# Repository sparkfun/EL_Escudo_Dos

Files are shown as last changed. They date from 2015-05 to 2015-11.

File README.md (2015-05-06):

SparkFun EL Escudo Dos
========================================

SparkFun EL Escudo Dos

[*SparkFun EL Escudo Dos (COM-10878)*](https://www.sparkfun.com/products/10878)

The SparkFun EL Escudo Dos is an Arduino shield for controlling up to eight strands of electroluminescent wire. 
EL wire is flexible plastic cord that glows brightly when high-voltage AC is applied to it.
The El Escudo Dos contains circuitry to safely switch high-voltage AC on and off, allowing you to create animated displays or whatever else your imagination can come up with.

Repository Contents
-------------------

* **/Firmware** - Example code 
* **/Hardware** - Eagle design files (.brd, .sch)
* **/Production** - Production panel files (.brd)

Documentation
--------------
* **[Hookup Guide](https://www.sparkfun.com/tutorials/353)** - Basic hookup guide for the EL Escudo Dos.
* **[SparkFun Fritzing repo](https://github.com/sparkfun/Fritzing_Parts)** - Fritzing diagrams for SparkFun products.
* **[SparkFun 3D Model repo](https://github.com/sparkfun/3D_Models)** - 3D models of SparkFun products. 

License Information
-------------------
This product is _**open source**_! 

The **hardware** is released under [Creative Commons ShareAlike 4.0 International](https://creativecommons.org/licenses/by-sa/4.0/).

The **code** is beerware; if you see me (or any other SparkFun employee) at the local, and you've found our code helpful, please buy us a round!

Please use, reuse, and modify these files as you see fit. Please maintain attribution to SparkFun Electronics and release anything derivative under the same license.

Distributed as-is; no warranty is given.

- Your friends at SparkFun.

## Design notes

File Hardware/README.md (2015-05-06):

SparkFun <PRODUCT NAME> Design Files
=====================================

The .sch and .brd files hare are Eagle CAD schematic and PCB design files from SparkFun Electronics.
A freeware version of Eagle can be found [here](http://www.cadsoftusa.com/download-eagle/freeware/). 

License
---------
This product is open source! 
The hardware is released under [Creative Commons ShareAlike 4.0 International](https://creativecommons.org/licenses/by-sa/4.0/).

Please use, reuse, and modify these files as you see fit. Please maintain attribution to SparkFun Electronics and release anything derivative under the same license.

Distributed as-is; no warranty is given.

- Your friends at SparkFun.

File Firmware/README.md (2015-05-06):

SparkFun EL Escudo Dos Firmware
===================================

* **SparkFun_EL_Example** - Arduino example for the EL Escudo Dos Shield

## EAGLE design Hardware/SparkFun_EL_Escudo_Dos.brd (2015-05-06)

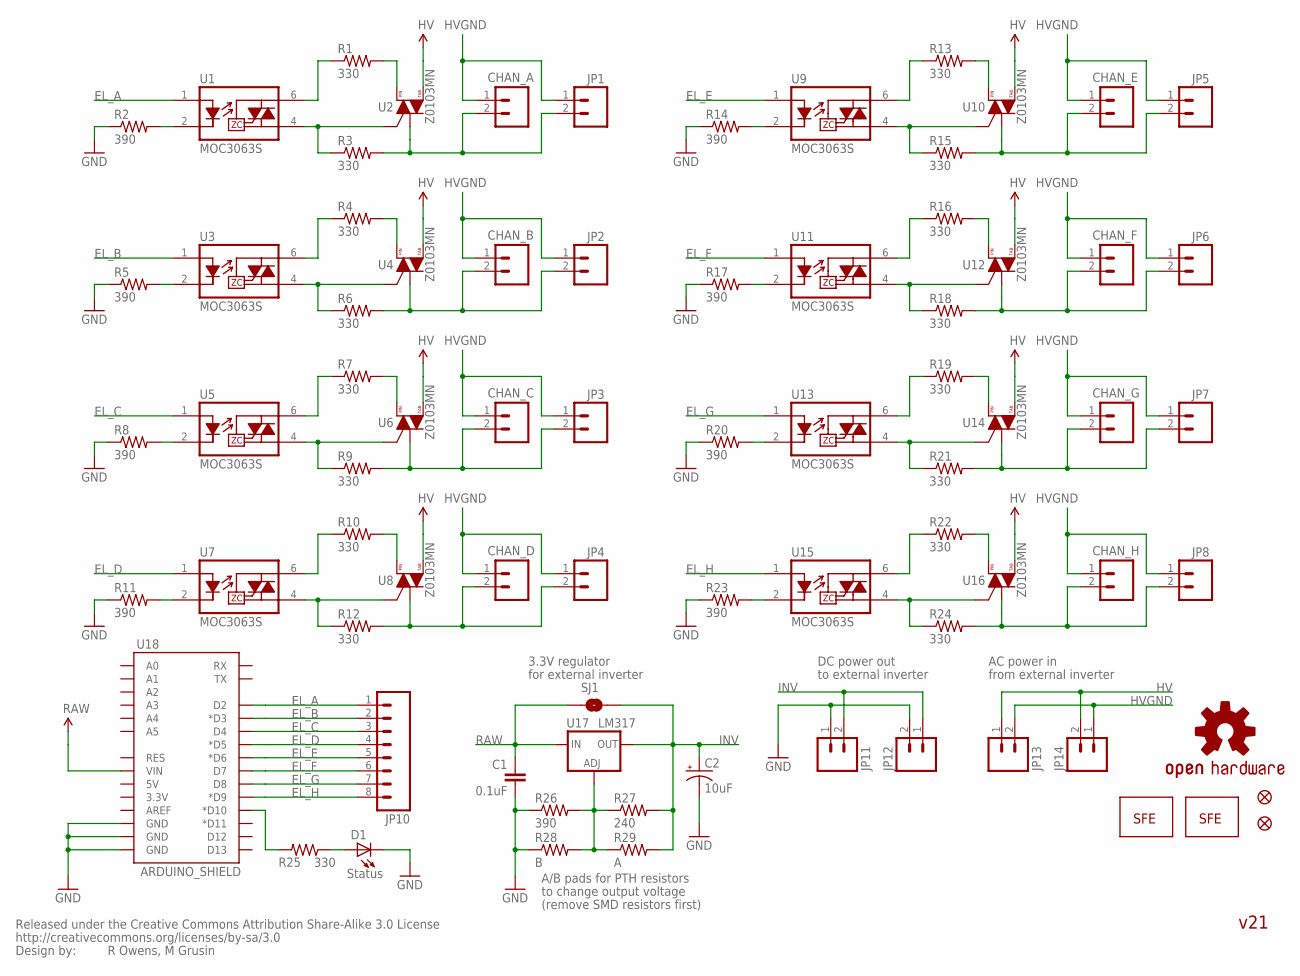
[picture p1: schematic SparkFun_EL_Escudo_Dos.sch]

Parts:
C1: 0.1uF; 0603-CAP
C2: 10uF; EIA3216
CHAN_A: M02-JST-2MM-SMT; JST-2-SMD
CHAN_B: M02-JST-2MM-SMT; JST-2-SMD
CHAN_C: M02-JST-2MM-SMT; JST-2-SMD
CHAN_D: M02-JST-2MM-SMT; JST-2-SMD
CHAN_E: M02-JST-2MM-SMT; JST-2-SMD
CHAN_F: M02-JST-2MM-SMT; JST-2-SMD
CHAN_G: M02-JST-2MM-SMT; JST-2-SMD
CHAN_H: M02-JST-2MM-SMT; JST-2-SMD
D1: Status; LED-0603
JP1, JP2, JP3, JP4, JP5, JP6, JP7, JP8, JP12, JP13: M02PTH; 1X02
JP9, JP15: LOGO-SFENEW; SFE-NEW-WEBLOGO
JP10: M081X08; 1X08
JP11, JP14: M02-JST-2MM-SMT; JST-2-SMD
JP16, JP17: FIDUCIALUFIDUCIAL; MICRO-FIDUCIAL
R1, R3, R4, R6, R7, R9, R10, R12, R13, R15, R16, R18, R19, R21, R22, R24, R25: 330; 0603-RES
R2, R5, R8, R11, R14, R17, R20, R23, R26: 390; 0603-RES
R27: 240; 0603-RES
R28: B; AXIAL-0.4
R29: A; AXIAL-0.4
SJ1: SOLDERJUMPERNO; SJ_2S-NO
U1, U3, U5, U7, U9, U11, U13, U15: MOC3063S; DIP8SMD
U2, U4, U6, U8, U10, U12, U14, U16: Z0103MN; SOT223
U17: LM317; V-REG_DPACK
U18: ARDUINO_SHIELD; DUEMILANOVE_SHIELD_NOLABELS
U$4: CREATIVE_COMMONS
U$5: OSHW-LOGOS; OSHW-LOGO-S

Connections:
EL_A: JP10.1, U1.1 (A), U18.D2
EL_B: JP10.2, U3.1 (A), U18.D3 (*D3)
EL_C: JP10.3, U5.1 (A), U18.D4
EL_D: JP10.4, U7.1 (A), U18.D5 (*D5)
EL_E: JP10.5, U9.1 (A), U18.D6 (*D6)
EL_F: JP10.6, U11.1 (A), U18.D7
EL_G: JP10.7, U13.1 (A), U18.D8
EL_H: JP10.8, U15.1 (A), U18.D9 (*D9)
GND: C1.2, C2.C (-), D1.C, JP11.1, JP12.2, R2.1, R5.1, R8.1, R11.1, R14.1, R17.1, R20.1, R23.1, R26.1, R28.P$1 (1), U18.GND@0 (GND), U18.GND@1 (GND), U18.GND@2 (GND)
HV: JP13.1, JP14.2, U2.4 (T2), U4.4 (T2), U6.4 (T2), U8.4 (T2), U10.4 (T2), U12.4 (T2), U14.4 (T2), U16.4 (T2)
HVGND: CHAN_A.1, CHAN_B.1, CHAN_C.1, CHAN_D.1, CHAN_E.1, CHAN_F.1, CHAN_G.1, CHAN_H.1, JP1.1, JP2.1, JP3.1, JP4.1, JP5.1, JP6.1, JP7.1, JP8.1, JP13.2, JP14.1
INV: C2.A (+), JP11.2, JP12.1, R27.2, R29.P$2 (2), SJ1.2, U17.4 (OUT)
unnamed: R2.2, U1.2 (K)
unnamed: R26.2, R27.1, R28.P$2 (2), R29.P$1 (1), U17.1 (ADJ)
unnamed: R1.1, U1.6 (T1)
unnamed: R25.2, U18.D10 (*D10)
unnamed: R6.1, U3.4 (T2), U4.3 (G)
unnamed: R5.2, U3.2 (K)
unnamed: R4.1, U3.6 (T1)
unnamed: CHAN_B.2, JP2.2, R6.2, U4.1 (T1)
unnamed: R1.2, U2.2 (T2)
unnamed: R9.1, U5.4 (T2), U6.3 (G)
unnamed: R8.2, U5.2 (K)
unnamed: R7.1, U5.6 (T1)
unnamed: CHAN_C.2, JP3.2, R9.2, U6.1 (T1)
unnamed: D1.A, R25.1
unnamed: R4.2, U4.2 (T2)
unnamed: R12.1, U7.4 (T2), U8.3 (G)
unnamed: R11.2, U7.2 (K)
unnamed: R10.1, U7.6 (T1)
unnamed: CHAN_D.2, JP4.2, R12.2, U8.1 (T1)
unnamed: R7.2, U6.2 (T2)
unnamed: CHAN_A.2, JP1.2, R3.2, U2.1 (T1)
unnamed: R15.1, U9.4 (T2), U10.3 (G)
unnamed: R14.2, U9.2 (K)
unnamed: R13.1, U9.6 (T1)
unnamed: CHAN_E.2, JP5.2, R15.2, U10.1 (T1)
unnamed: R10.2, U8.2 (T2)
unnamed: R18.1, U11.4 (T2), U12.3 (G)
unnamed: R17.2, U11.2 (K)
unnamed: R16.1, U11.6 (T1)
unnamed: CHAN_F.2, JP6.2, R18.2, U12.1 (T1)
unnamed: R13.2, U10.2 (T2)
unnamed: R21.1, U13.4 (T2), U14.3 (G)
unnamed: R20.2, U13.2 (K)
unnamed: R19.1, U13.6 (T1)
unnamed: CHAN_G.2, JP7.2, R21.2, U14.1 (T1)
unnamed: R16.2, U12.2 (T2)
unnamed: R24.1, U15.4 (T2), U16.3 (G)
unnamed: R23.2, U15.2 (K)
unnamed: R22.1, U15.6 (T1)
unnamed: CHAN_H.2, JP8.2, R24.2, U16.1 (T1)
unnamed: R19.2, U14.2 (T2)
unnamed: R22.2, U16.2 (T2)
unnamed: R3.1, U1.4 (T2), U2.3 (G)
RAW: C1.1, SJ1.1, U17.3 (IN), U18.VIN

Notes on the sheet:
AC power in
from external inverter
DC power out
to external inverter
3.3V regulator
R Owens, M Grusin
for external inverter
A/B pads for PTH resistors
to change output voltage
(remove SMD resistors first)
v21

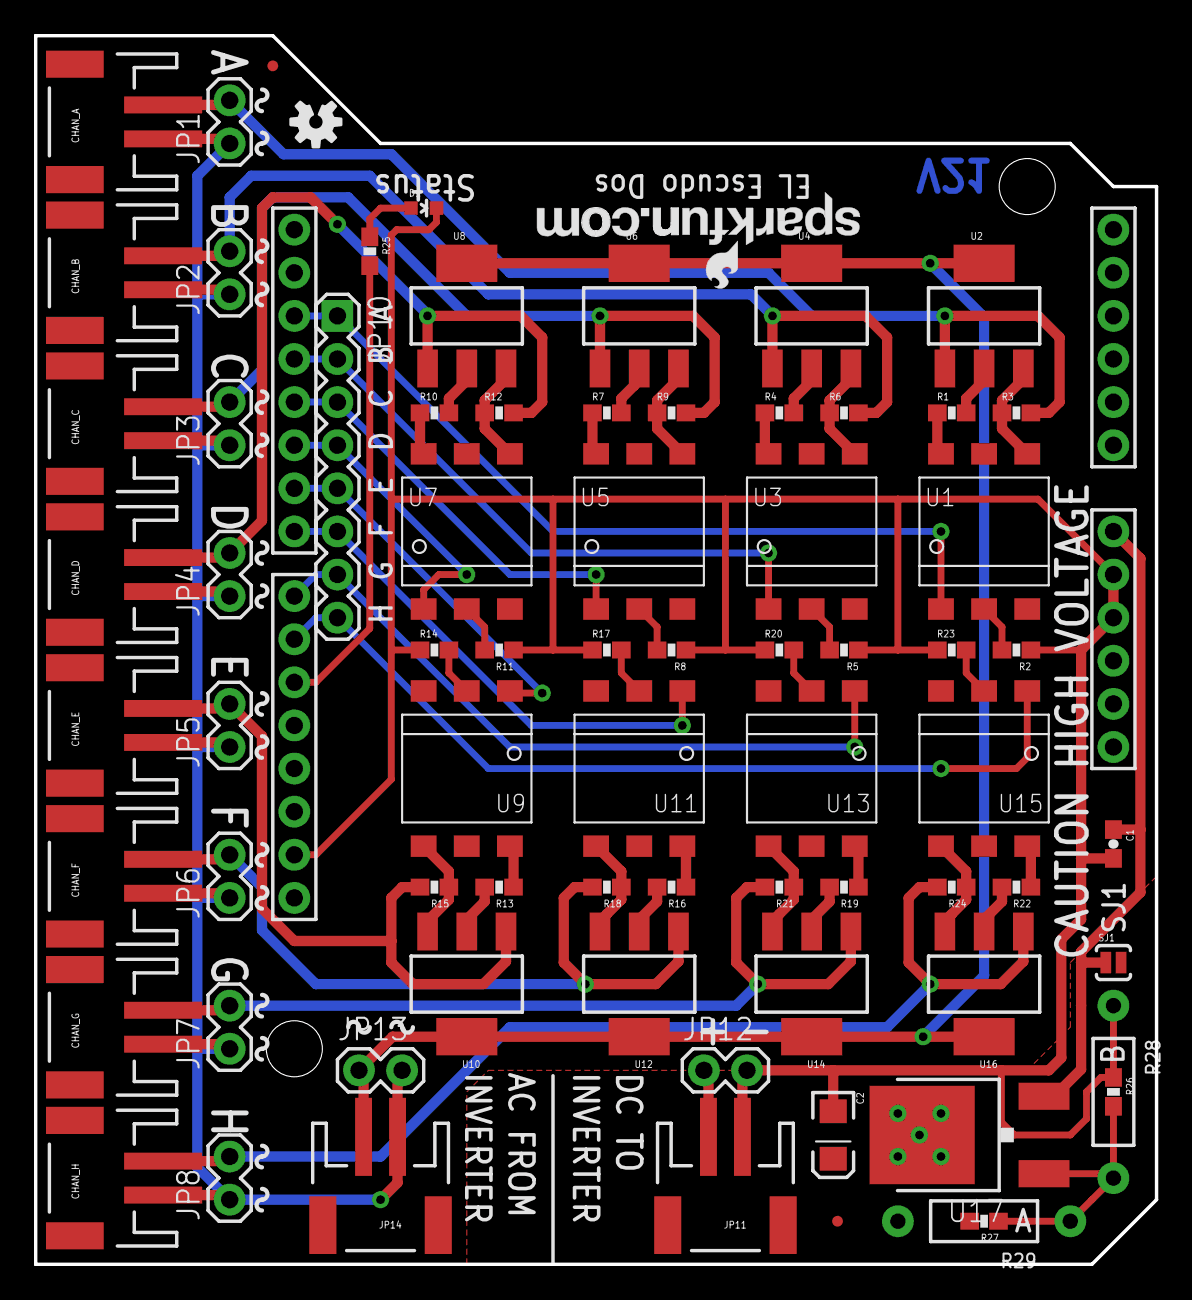
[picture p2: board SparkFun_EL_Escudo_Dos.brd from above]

Board: 2 copper layers, 66.0 x 72.4 mm, 78 parts (1 on the bottom side), 56 nets.

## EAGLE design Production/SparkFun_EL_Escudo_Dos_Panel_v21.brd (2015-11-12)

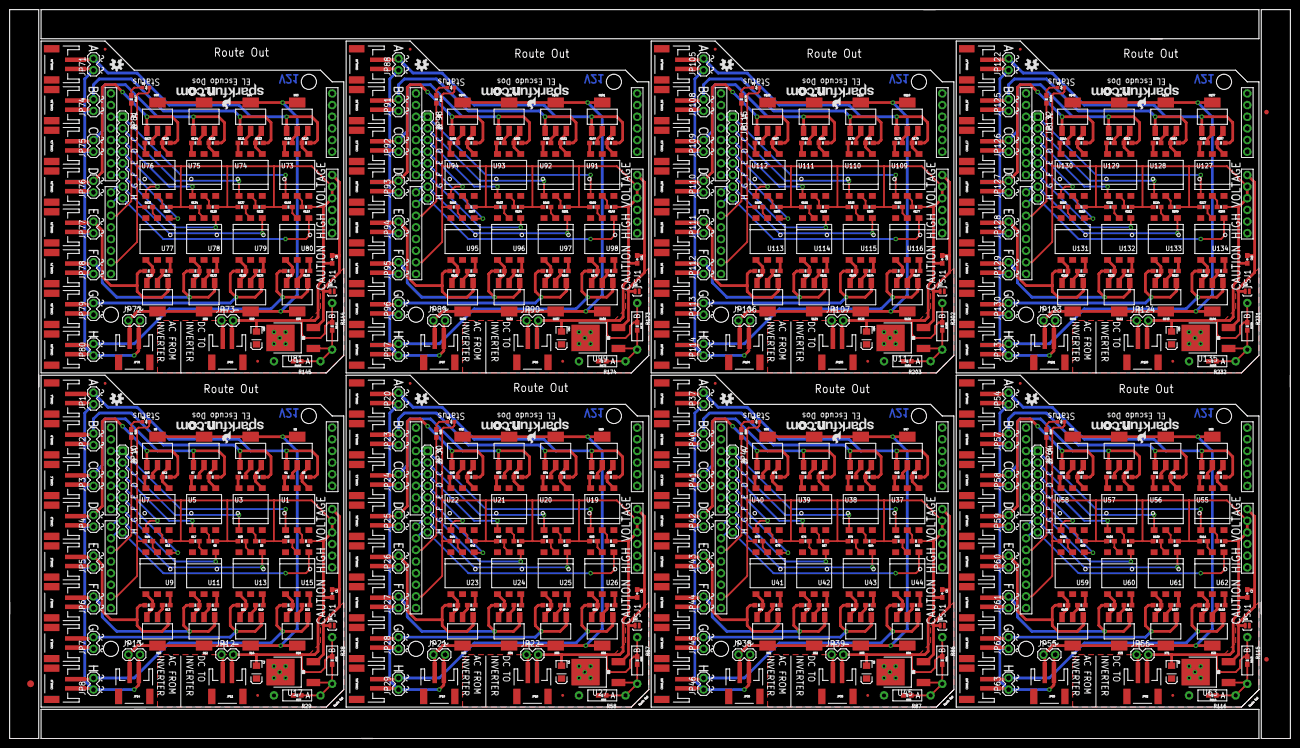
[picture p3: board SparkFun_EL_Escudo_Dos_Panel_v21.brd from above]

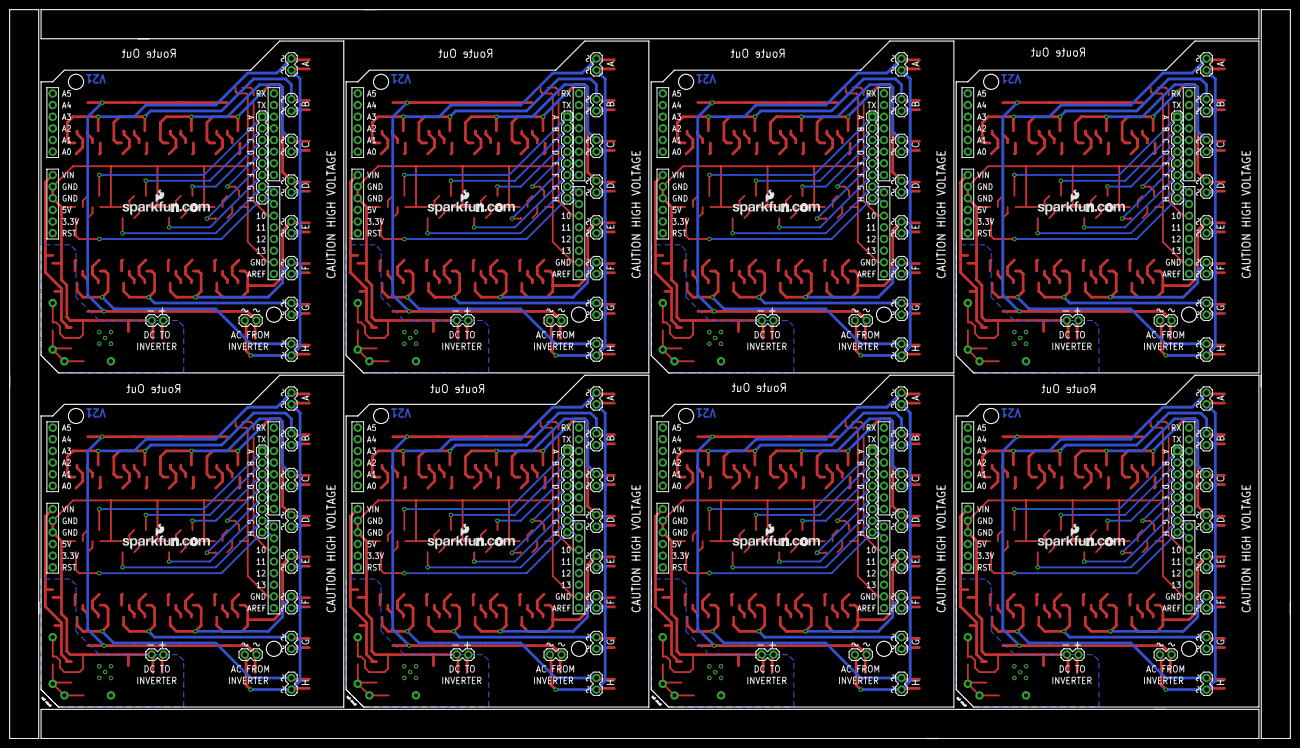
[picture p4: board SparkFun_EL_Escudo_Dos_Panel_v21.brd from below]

Board: 2 copper layers, 279.4 x 159.0 mm, 619 parts (8 on the bottom side), 448 nets.

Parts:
C1, C3, C5, C7, C9, C11, C13, C15: 0.1uF; 0603-CAP
C2, C4, C6, C8, C10, C12, C14, C16: 10uF; EIA3216
CHAN_A, CHAN_A1, CHAN_A2, CHAN_A3, CHAN_A4, CHAN_A5, CHAN_A6, CHAN_A7: JST-2-SMD
CHAN_B, CHAN_B1, CHAN_B2, CHAN_B3, CHAN_B4, CHAN_B5, CHAN_B6, CHAN_B7: JST-2-SMD
CHAN_C, CHAN_C1, CHAN_C2, CHAN_C3, CHAN_C4, CHAN_C5, CHAN_C6, CHAN_C7: JST-2-SMD
CHAN_D, CHAN_D1, CHAN_D2, CHAN_D3, CHAN_D4, CHAN_D5, CHAN_D6, CHAN_D7: JST-2-SMD
CHAN_E, CHAN_E1, CHAN_E2, CHAN_E3, CHAN_E4, CHAN_E5, CHAN_E6, CHAN_E7: JST-2-SMD
CHAN_F, CHAN_F1, CHAN_F2, CHAN_F3, CHAN_F4, CHAN_F5, CHAN_F6, CHAN_F7: JST-2-SMD
CHAN_G, CHAN_G1, CHAN_G2, CHAN_G3, CHAN_G4, CHAN_G5, CHAN_G6, CHAN_G7: JST-2-SMD
CHAN_H, CHAN_H1, CHAN_H2, CHAN_H3, CHAN_H4, CHAN_H5, CHAN_H6, CHAN_H7: JST-2-SMD
D1, D2, D3, D4, D5, D6, D7, D8: Status; LED-0603
E$1: FIDUCIAL-1.5X3
E$5, E$6: FIDUCIAL-1X2
JP1, JP2, JP3, JP4, JP5, JP6, JP7, JP8, JP12, JP13, JP20, JP21, JP22, JP23, JP24, JP25, JP26, JP27, JP28, JP29, JP37, JP38, JP39, JP40, JP41, JP42, JP43, JP44, JP45, JP46, JP54, JP55, JP56, JP57, JP58, JP59, JP60, JP61, JP62, JP63, JP71, JP72, JP73, JP74, JP75, JP76, JP77, JP78, JP79, JP80, JP88, JP89, JP90, JP91, JP92, JP93, JP94, JP95, JP96, JP97, JP105, JP106, JP107, JP108, JP109, JP110, JP111, JP112, JP113, JP114, JP122, JP123, JP124, JP125, JP126, JP127, JP128, JP129, JP130, JP131: 1X02
JP9, JP15, JP31, JP32, JP48, JP49, JP65, JP66, JP82, JP83, JP99, JP100, JP116, JP117, JP133, JP134: LOGO-SFENEW; SFE-NEW-WEBLOGO
JP10, JP30, JP47, JP64, JP81, JP98, JP115, JP132: 1X08
JP11, JP14, JP18, JP19, JP35, JP36, JP52, JP53, JP69, JP70, JP86, JP87, JP103, JP104, JP120, JP121: JST-2-SMD
JP16, JP17, JP33, JP34, JP50, JP51, JP67, JP68, JP84, JP85, JP101, JP102, JP118, JP119, JP135, JP136: FIDUCIALUFIDUCIAL; MICRO-FIDUCIAL
R1, R3, R4, R6, R7, R9, R10, R12, R13, R15, R16, R18, R19, R21, R22, R24, R25, R30, R31, R33, R34, R36, R37, R39, R40, R42, R43, R45, R46, R48, R49, R51, R52, R54, R59, R60, R62, R63, R65, R66, R68, R69, R71, R72, R74, R75, R77, R78, R80, R81, R83, R88, R89, R91, R92, R94, R95, R97, R98, R100, R101, R103, R104, R106, R107, R109, R110, R112, R117, R118, R120, R121, R123, R124, R126, R127, R129, R130, R132, R133, R135, R136, R138, R139, R141, R146, R147, R149, R150, R152, R153, R155, R156, R158, R159, R161, R162, R164, R165, R167, R168, R170, R175, R176, R178, R179, R181, R182, R184, R185, R187, R188, R190, R191, R193, R194, R196, R197, R199, R204, R205, R207, R208, R210, R211, R213, R214, R216, R217, R219, R220, R222, R223, R225, R226, R228: 330; 0603-RES
R2, R5, R8, R11, R14, R17, R20, R23, R26, R32, R35, R38, R41, R44, R47, R50, R53, R55, R61, R64, R67, R70, R73, R76, R79, R82, R84, R90, R93, R96, R99, R102, R105, R108, R111, R113, R119, R122, R125, R128, R131, R134, R137, R140, R142, R148, R151, R154, R157, R160, R163, R166, R169, R171, R177, R180, R183, R186, R189, R192, R195, R198, R200, R206, R209, R212, R215, R218, R221, R224, R227, R229: 390; 0603-RES
R27, R56, R85, R114, R143, R172, R201, R230: 240; 0603-RES
R28, R57, R86, R115, R144, R173, R202, R231: B; AXIAL-0.4
R29, R58, R87, R116, R145, R174, R203, R232: A; AXIAL-0.4
SJ1, SJ2, SJ3, SJ4, SJ5, SJ6, SJ7, SJ8: SJ_2S-NO
U1, U3, U5, U7, U9, U11, U13, U15, U19, U20, U21, U22, U23, U24, U25, U26, U37, U38, U39, U40, U41, U42, U43, U44, U55, U56, U57, U58, U59, U60, U61, U62, U73, U74, U75, U76, U77, U78, U79, U80, U91, U92, U93, U94, U95, U96, U97, U98, U109, U110, U111, U112, U113, U114, U115, U116, U127, U128, U129, U130, U131, U132, U133, U134: MOC3063S; DIP8SMD
U2, U4, U6, U8, U10, U12, U14, U16, U29, U30, U31, U32, U33, U34, U35, U36, U47, U48, U49, U50, U51, U52, U53, U54, U65, U66, U67, U68, U69, U70, U71, U72, U83, U84, U85, U86, U87, U88, U89, U90, U101, U102, U103, U104, U105, U106, U107, U108, U119, U120, U121, U122, U123, U124, U125, U126, U137, U138, U139, U140, U141, U142, U143, U144: Z0103MN; SOT223
U17, U27, U45, U63, U81, U99, U117, U135: LM317; V-REG_DPACK
U18, U28, U46, U64, U82, U100, U118, U136: ARDUINO_SHIELD; DUEMILANOVE_SHIELD_NOLABELS
U$1, U$2, U$3, U$4, U$5, U$6, U$7, U$8: OSHW-LOGOS; OSHW-LOGO-S

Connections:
EL_A: JP10.1, U1.1, U18.D2
EL_A1: JP30.1, U19.1, U28.D2
EL_A2: JP47.1, U37.1, U46.D2
EL_A3: JP64.1, U55.1, U64.D2
EL_A4: JP81.1, U73.1, U82.D2
EL_A5: JP98.1, U91.1, U100.D2
EL_A6: JP115.1, U109.1, U118.D2
EL_A7: JP132.1, U127.1, U136.D2
EL_B: JP10.2, U3.1, U18.D3
EL_B1: JP30.2, U20.1, U28.D3
EL_B2: JP47.2, U38.1, U46.D3
EL_B3: JP64.2, U56.1, U64.D3
EL_B4: JP81.2, U74.1, U82.D3
EL_B5: JP98.2, U92.1, U100.D3
EL_B6: JP115.2, U110.1, U118.D3
EL_B7: JP132.2, U128.1, U136.D3
EL_C: JP10.3, U5.1, U18.D4
EL_C1: JP30.3, U21.1, U28.D4
EL_C2: JP47.3, U39.1, U46.D4
EL_C3: JP64.3, U57.1, U64.D4
EL_C4: JP81.3, U75.1, U82.D4
EL_C5: JP98.3, U93.1, U100.D4
EL_C6: JP115.3, U111.1, U118.D4
EL_C7: JP132.3, U129.1, U136.D4
EL_D: JP10.4, U7.1, U18.D5
EL_D1: JP30.4, U22.1, U28.D5
EL_D2: JP47.4, U40.1, U46.D5
EL_D3: JP64.4, U58.1, U64.D5
EL_D4: JP81.4, U76.1, U82.D5
EL_D5: JP98.4, U94.1, U100.D5
EL_D6: JP115.4, U112.1, U118.D5
EL_D7: JP132.4, U130.1, U136.D5
EL_E: JP10.5, U9.1, U18.D6
EL_E1: JP30.5, U23.1, U28.D6
EL_E2: JP47.5, U41.1, U46.D6
EL_E3: JP64.5, U59.1, U64.D6
EL_E4: JP81.5, U77.1, U82.D6
EL_E5: JP98.5, U95.1, U100.D6
EL_E6: JP115.5, U113.1, U118.D6
EL_E7: JP132.5, U131.1, U136.D6
EL_F: JP10.6, U11.1, U18.D7
EL_F1: JP30.6, U24.1, U28.D7
EL_F2: JP47.6, U42.1, U46.D7
EL_F3: JP64.6, U60.1, U64.D7
EL_F4: JP81.6, U78.1, U82.D7
EL_F5: JP98.6, U96.1, U100.D7
EL_F6: JP115.6, U114.1, U118.D7
EL_F7: JP132.6, U132.1, U136.D7
EL_G: JP10.7, U13.1, U18.D8
EL_G1: JP30.7, U25.1, U28.D8
EL_G2: JP47.7, U43.1, U46.D8
EL_G3: JP64.7, U61.1, U64.D8
EL_G4: JP81.7, U79.1, U82.D8
EL_G5: JP98.7, U97.1, U100.D8
EL_G6: JP115.7, U115.1, U118.D8
EL_G7: JP132.7, U133.1, U136.D8
EL_H: JP10.8, U15.1, U18.D9
EL_H1: JP30.8, U26.1, U28.D9
EL_H2: JP47.8, U44.1, U46.D9
EL_H3: JP64.8, U62.1, U64.D9
EL_H4: JP81.8, U80.1, U82.D9
EL_H5: JP98.8, U98.1, U100.D9
EL_H6: JP115.8, U116.1, U118.D9
EL_H7: JP132.8, U134.1, U136.D9
GND: C1.2, C2.C, D1.C, JP11.1, JP12.2, R2.1, R5.1, R8.1, R11.1, R14.1, R17.1, R20.1, R23.1, R26.1, R28.P$1, U18.GND@0, U18.GND@1, U18.GND@2
GND1: C3.2, C4.C, D2.C, JP18.1, JP22.2, R32.1, R35.1, R38.1, R41.1, R44.1, R47.1, R50.1, R53.1, R55.1, R57.P$1, U28.GND@0, U28.GND@1, U28.GND@2
GND2: C5.2, C6.C, D3.C, JP35.1, JP39.2, R61.1, R64.1, R67.1, R70.1, R73.1, R76.1, R79.1, R82.1, R84.1, R86.P$1, U46.GND@0, U46.GND@1, U46.GND@2
GND3: C7.2, C8.C, D4.C, JP52.1, JP56.2, R90.1, R93.1, R96.1, R99.1, R102.1, R105.1, R108.1, R111.1, R113.1, R115.P$1, U64.GND@0, U64.GND@1, U64.GND@2
GND4: C9.2, C10.C, D5.C, JP69.1, JP73.2, R119.1, R122.1, R125.1, R128.1, R131.1, R134.1, R137.1, R140.1, R142.1, R144.P$1, U82.GND@0, U82.GND@1, U82.GND@2
GND5: C11.2, C12.C, D6.C, JP86.1, JP90.2, R148.1, R151.1, R154.1, R157.1, R160.1, R163.1, R166.1, R169.1, R171.1, R173.P$1, U100.GND@0, U100.GND@1, U100.GND@2
GND6: C13.2, C14.C, D7.C, JP103.1, JP107.2, R177.1, R180.1, R183.1, R186.1, R189.1, R192.1, R195.1, R198.1, R200.1, R202.P$1, U118.GND@0, U118.GND@1, U118.GND@2
GND7: C15.2, C16.C, D8.C, JP120.1, JP124.2, R206.1, R209.1, R212.1, R215.1, R218.1, R221.1, R224.1, R227.1, R229.1, R231.P$1, U136.GND@0, U136.GND@1, U136.GND@2
HV: JP13.1, JP14.2, U2.4, U4.4, U6.4, U8.4, U10.4, U12.4, U14.4, U16.4
HV1: JP19.2, JP21.1, U29.4, U30.4, U31.4, U32.4, U33.4, U34.4, U35.4, U36.4
HV2: JP36.2, JP38.1, U47.4, U48.4, U49.4, U50.4, U51.4, U52.4, U53.4, U54.4
HV3: JP53.2, JP55.1, U65.4, U66.4, U67.4, U68.4, U69.4, U70.4, U71.4, U72.4
HV4: JP70.2, JP72.1, U83.4, U84.4, U85.4, U86.4, U87.4, U88.4, U89.4, U90.4
HV5: JP87.2, JP89.1, U101.4, U102.4, U103.4, U104.4, U105.4, U106.4, U107.4, U108.4
HV6: JP104.2, JP106.1, U119.4, U120.4, U121.4, U122.4, U123.4, U124.4, U125.4, U126.4
HV7: JP121.2, JP123.1, U137.4, U138.4, U139.4, U140.4, U141.4, U142.4, U143.4, U144.4
HVGND: CHAN_A.1, CHAN_B.1, CHAN_C.1, CHAN_D.1, CHAN_E.1, CHAN_F.1, CHAN_G.1, CHAN_H.1, JP1.1, JP2.1, JP3.1, JP4.1, JP5.1, JP6.1, JP7.1, JP8.1, JP13.2, JP14.1
HVGND1: CHAN_A1.1, CHAN_B1.1, CHAN_C1.1, CHAN_D1.1, CHAN_E1.1, CHAN_F1.1, CHAN_G1.1, CHAN_H1.1, JP19.1, JP20.1, JP21.2, JP23.1, JP24.1, JP25.1, JP26.1, JP27.1, JP28.1, JP29.1
HVGND2: CHAN_A2.1, CHAN_B2.1, CHAN_C2.1, CHAN_D2.1, CHAN_E2.1, CHAN_F2.1, CHAN_G2.1, CHAN_H2.1, JP36.1, JP37.1, JP38.2, JP40.1, JP41.1, JP42.1, JP43.1, JP44.1, JP45.1, JP46.1
HVGND3: CHAN_A3.1, CHAN_B3.1, CHAN_C3.1, CHAN_D3.1, CHAN_E3.1, CHAN_F3.1, CHAN_G3.1, CHAN_H3.1, JP53.1, JP54.1, JP55.2, JP57.1, JP58.1, JP59.1, JP60.1, JP61.1, JP62.1, JP63.1
HVGND4: CHAN_A4.1, CHAN_B4.1, CHAN_C4.1, CHAN_D4.1, CHAN_E4.1, CHAN_F4.1, CHAN_G4.1, CHAN_H4.1, JP70.1, JP71.1, JP72.2, JP74.1, JP75.1, JP76.1, JP77.1, JP78.1, JP79.1, JP80.1
HVGND5: CHAN_A5.1, CHAN_B5.1, CHAN_C5.1, CHAN_D5.1, CHAN_E5.1, CHAN_F5.1, CHAN_G5.1, CHAN_H5.1, JP87.1, JP88.1, JP89.2, JP91.1, JP92.1, JP93.1, JP94.1, JP95.1, JP96.1, JP97.1
HVGND6: CHAN_A6.1, CHAN_B6.1, CHAN_C6.1, CHAN_D6.1, CHAN_E6.1, CHAN_F6.1, CHAN_G6.1, CHAN_H6.1, JP104.1, JP105.1, JP106.2, JP108.1, JP109.1, JP110.1, JP111.1, JP112.1, JP113.1, JP114.1
HVGND7: CHAN_A7.1, CHAN_B7.1, CHAN_C7.1, CHAN_D7.1, CHAN_E7.1, CHAN_F7.1, CHAN_G7.1, CHAN_H7.1, JP121.1, JP122.1, JP123.2, JP125.1, JP126.1, JP127.1, JP128.1, JP129.1, JP130.1, JP131.1
INV: C2.A, JP11.2, JP12.1, R27.2, R29.P$2, SJ1.2, U17.4
INV1: C4.A, JP18.2, JP22.1, R56.2, R58.P$2, SJ2.2, U27.4
INV2: C6.A, JP35.2, JP39.1, R85.2, R87.P$2, SJ3.2, U45.4
INV3: C8.A, JP52.2, JP56.1, R114.2, R116.P$2, SJ4.2, U63.4
INV4: C10.A, JP69.2, JP73.1, R143.2, R145.P$2, SJ5.2, U81.4
INV5: C12.A, JP86.2, JP90.1, R172.2, R174.P$2, SJ6.2, U99.4
INV6: C14.A, JP103.2, JP107.1, R201.2, R203.P$2, SJ7.2, U117.4
INV7: C16.A, JP120.2, JP124.1, R230.2, R232.P$2, SJ8.2, U135.4
unnamed: R2.2, U1.2
unnamed: R26.2, R27.1, R28.P$2, R29.P$1, U17.1
unnamed: R1.1, U1.6
unnamed: R25.2, U18.D10
unnamed: R6.1, U3.4, U4.3
unnamed: R5.2, U3.2
unnamed: R4.1, U3.6
unnamed: CHAN_B.2, JP2.2, R6.2, U4.1
unnamed: R1.2, U2.2
unnamed: R9.1, U5.4, U6.3
unnamed: R8.2, U5.2
unnamed: R7.1, U5.6
unnamed: CHAN_C.2, JP3.2, R9.2, U6.1
unnamed: D1.A, R25.1
unnamed: R4.2, U4.2
unnamed: R12.1, U7.4, U8.3
unnamed: R11.2, U7.2
unnamed: R10.1, U7.6
unnamed: CHAN_D.2, JP4.2, R12.2, U8.1
unnamed: R7.2, U6.2
unnamed: CHAN_A.2, JP1.2, R3.2, U2.1
unnamed: R15.1, U9.4, U10.3
unnamed: R14.2, U9.2
unnamed: R13.1, U9.6
unnamed: CHAN_E.2, JP5.2, R15.2, U10.1
unnamed: R10.2, U8.2
unnamed: R18.1, U11.4, U12.3
unnamed: R17.2, U11.2
unnamed: R16.1, U11.6
unnamed: CHAN_F.2, JP6.2, R18.2, U12.1
unnamed: R13.2, U10.2
unnamed: R21.1, U13.4, U14.3
unnamed: R20.2, U13.2
unnamed: R19.1, U13.6
unnamed: CHAN_G.2, JP7.2, R21.2, U14.1
unnamed: R16.2, U12.2
unnamed: R24.1, U15.4, U16.3
unnamed: R23.2, U15.2
unnamed: R22.1, U15.6
unnamed: CHAN_H.2, JP8.2, R24.2, U16.1
unnamed: R19.2, U14.2
unnamed: R22.2, U16.2
unnamed: D2.A, R30.1
unnamed: R33.1, U19.4, U29.3
unnamed: R32.2, U19.2
unnamed: R31.1, U19.6
unnamed: CHAN_A1.2, JP20.2, R33.2, U29.1
unnamed: R36.1, U20.4, U30.3
unnamed: R35.2, U20.2
unnamed: R34.1, U20.6
unnamed: CHAN_B1.2, JP23.2, R36.2, U30.1
unnamed: R39.1, U21.4, U31.3
unnamed: R38.2, U21.2
unnamed: R37.1, U21.6
unnamed: CHAN_C1.2, JP24.2, R39.2, U31.1
unnamed: R42.1, U22.4, U32.3
unnamed: R41.2, U22.2
unnamed: R40.1, U22.6
unnamed: CHAN_D1.2, JP25.2, R42.2, U32.1
unnamed: R45.1, U23.4, U33.3
unnamed: R44.2, U23.2
unnamed: R43.1, U23.6
unnamed: CHAN_E1.2, JP26.2, R45.2, U33.1
unnamed: R48.1, U24.4, U34.3
unnamed: R47.2, U24.2
unnamed: R46.1, U24.6
unnamed: CHAN_F1.2, JP27.2, R48.2, U34.1
unnamed: R51.1, U25.4, U35.3
unnamed: R50.2, U25.2
unnamed: R49.1, U25.6
unnamed: CHAN_G1.2, JP28.2, R51.2, U35.1
unnamed: R54.1, U26.4, U36.3
unnamed: R53.2, U26.2
unnamed: R52.1, U26.6
unnamed: CHAN_H1.2, JP29.2, R54.2, U36.1
unnamed: R55.2, R56.1, R57.P$2, R58.P$1, U27.1
unnamed: R31.2, U29.2
unnamed: R34.2, U30.2
unnamed: R37.2, U31.2
unnamed: R40.2, U32.2
unnamed: R43.2, U33.2
unnamed: R46.2, U34.2
unnamed: R49.2, U35.2
unnamed: R52.2, U36.2
unnamed: R30.2, U28.D10
unnamed: D3.A, R59.1
unnamed: R62.1, U37.4, U47.3
unnamed: R61.2, U37.2
unnamed: R60.1, U37.6
unnamed: CHAN_A2.2, JP37.2, R62.2, U47.1
unnamed: R65.1, U38.4, U48.3
unnamed: R64.2, U38.2
unnamed: R63.1, U38.6
unnamed: CHAN_B2.2, JP40.2, R65.2, U48.1
unnamed: R68.1, U39.4, U49.3
unnamed: R67.2, U39.2
unnamed: R66.1, U39.6
unnamed: CHAN_C2.2, JP41.2, R68.2, U49.1
unnamed: R71.1, U40.4, U50.3
unnamed: R70.2, U40.2
unnamed: R69.1, U40.6
unnamed: CHAN_D2.2, JP42.2, R71.2, U50.1
unnamed: R74.1, U41.4, U51.3
unnamed: R73.2, U41.2
unnamed: R72.1, U41.6
unnamed: CHAN_E2.2, JP43.2, R74.2, U51.1
unnamed: R77.1, U42.4, U52.3
unnamed: R76.2, U42.2
unnamed: R75.1, U42.6
unnamed: CHAN_F2.2, JP44.2, R77.2, U52.1
unnamed: R80.1, U43.4, U53.3
unnamed: R79.2, U43.2
unnamed: R78.1, U43.6
unnamed: CHAN_G2.2, JP45.2, R80.2, U53.1
unnamed: R83.1, U44.4, U54.3
unnamed: R82.2, U44.2
unnamed: R3.1, U1.4, U2.3
unnamed: R81.1, U44.6
unnamed: CHAN_H2.2, JP46.2, R83.2, U54.1
unnamed: R84.2, R85.1, R86.P$2, R87.P$1, U45.1
unnamed: R60.2, U47.2
unnamed: R63.2, U48.2
unnamed: R66.2, U49.2
unnamed: R69.2, U50.2
unnamed: R72.2, U51.2
unnamed: R75.2, U52.2
unnamed: R78.2, U53.2
unnamed: R81.2, U54.2
unnamed: R59.2, U46.D10
unnamed: D4.A, R88.1
unnamed: R91.1, U55.4, U65.3
unnamed: R90.2, U55.2
unnamed: R89.1, U55.6
unnamed: CHAN_A3.2, JP54.2, R91.2, U65.1
unnamed: R94.1, U56.4, U66.3
unnamed: R93.2, U56.2
unnamed: R92.1, U56.6
unnamed: CHAN_B3.2, JP57.2, R94.2, U66.1
unnamed: R97.1, U57.4, U67.3
unnamed: R96.2, U57.2
unnamed: R95.1, U57.6
unnamed: CHAN_C3.2, JP58.2, R97.2, U67.1
unnamed: R100.1, U58.4, U68.3
unnamed: R99.2, U58.2
unnamed: R98.1, U58.6
unnamed: CHAN_D3.2, JP59.2, R100.2, U68.1
unnamed: R103.1, U59.4, U69.3
unnamed: R102.2, U59.2
unnamed: R101.1, U59.6
unnamed: CHAN_E3.2, JP60.2, R103.2, U69.1
unnamed: R106.1, U60.4, U70.3
unnamed: R105.2, U60.2
unnamed: R104.1, U60.6
unnamed: CHAN_F3.2, JP61.2, R106.2, U70.1
unnamed: R109.1, U61.4, U71.3
unnamed: R108.2, U61.2
unnamed: R107.1, U61.6
unnamed: CHAN_G3.2, JP62.2, R109.2, U71.1
unnamed: R112.1, U62.4, U72.3
unnamed: R111.2, U62.2
unnamed: R110.1, U62.6
unnamed: CHAN_H3.2, JP63.2, R112.2, U72.1
unnamed: R113.2, R114.1, R115.P$2, R116.P$1, U63.1
unnamed: R89.2, U65.2
unnamed: R92.2, U66.2
unnamed: R95.2, U67.2
unnamed: R98.2, U68.2
unnamed: R101.2, U69.2
unnamed: R104.2, U70.2
unnamed: R107.2, U71.2
unnamed: R110.2, U72.2
unnamed: R88.2, U64.D10
unnamed: D5.A, R117.1
unnamed: R120.1, U73.4, U83.3
unnamed: R119.2, U73.2
unnamed: R118.1, U73.6
unnamed: CHAN_A4.2, JP71.2, R120.2, U83.1
unnamed: R123.1, U74.4, U84.3
unnamed: R122.2, U74.2
unnamed: R121.1, U74.6
unnamed: CHAN_B4.2, JP74.2, R123.2, U84.1
unnamed: R126.1, U75.4, U85.3
unnamed: R125.2, U75.2
unnamed: R124.1, U75.6
unnamed: CHAN_C4.2, JP75.2, R126.2, U85.1
unnamed: R129.1, U76.4, U86.3
unnamed: R128.2, U76.2
unnamed: R127.1, U76.6
unnamed: CHAN_D4.2, JP76.2, R129.2, U86.1
unnamed: R132.1, U77.4, U87.3
unnamed: R131.2, U77.2
unnamed: R130.1, U77.6
unnamed: CHAN_E4.2, JP77.2, R132.2, U87.1
unnamed: R135.1, U78.4, U88.3
unnamed: R134.2, U78.2
unnamed: R133.1, U78.6
unnamed: CHAN_F4.2, JP78.2, R135.2, U88.1
unnamed: R138.1, U79.4, U89.3
unnamed: R137.2, U79.2
unnamed: R136.1, U79.6
unnamed: CHAN_G4.2, JP79.2, R138.2, U89.1
unnamed: R141.1, U80.4, U90.3
unnamed: R140.2, U80.2
unnamed: R139.1, U80.6
unnamed: CHAN_H4.2, JP80.2, R141.2, U90.1
unnamed: R142.2, R143.1, R144.P$2, R145.P$1, U81.1
unnamed: R118.2, U83.2
unnamed: R121.2, U84.2
unnamed: R124.2, U85.2
unnamed: R127.2, U86.2
unnamed: R130.2, U87.2
unnamed: R133.2, U88.2
unnamed: R136.2, U89.2
unnamed: R139.2, U90.2
unnamed: R117.2, U82.D10
unnamed: D6.A, R146.1
unnamed: R149.1, U91.4, U101.3
unnamed: R148.2, U91.2
unnamed: R147.1, U91.6
unnamed: CHAN_A5.2, JP88.2, R149.2, U101.1
unnamed: R152.1, U92.4, U102.3
unnamed: R151.2, U92.2
unnamed: R150.1, U92.6
unnamed: CHAN_B5.2, JP91.2, R152.2, U102.1
unnamed: R155.1, U93.4, U103.3
unnamed: R154.2, U93.2
unnamed: R153.1, U93.6
unnamed: CHAN_C5.2, JP92.2, R155.2, U103.1
unnamed: R158.1, U94.4, U104.3
unnamed: R157.2, U94.2
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

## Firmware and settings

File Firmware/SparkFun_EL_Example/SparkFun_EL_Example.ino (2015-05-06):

/***************************************************************************
SparkFun_EL_Example
Mike Grusin @ SparkFun Electronics 2012
Updated by Toni Klopfenstein@ SparkFun Electronics April 2015
https://github.com/sparkfun/EL_Sequencer

Test sketch for the EL Escudo Dos and EL Sequencer. 
It turns each EL channel (A-H) on in sequence and repeats said loop. 

Development environment specifics:
Arduino 1.6.3

This code is beerware; if you see me (or any other SparkFun employee) at the local, and you've found our code helpful, please buy us a round!
Distributed as-is; no warranty is given.
****************************************************************************/

/*******************Setup Loop***************************/
void setup() {                
  // The EL channels are on pins 2 through 9 on the ATMega328
  // Initialize the pins as outputs
  pinMode(2, OUTPUT);  // channel A  
  pinMode(3, OUTPUT);  // channel B   
  pinMode(4, OUTPUT);  // channel C
  pinMode(5, OUTPUT);  // channel D    
  pinMode(6, OUTPUT);  // channel E
  pinMode(7, OUTPUT);  // channel F
  pinMode(8, OUTPUT);  // channel G
  pinMode(9, OUTPUT);  // channel H

//Uncomment the following line if using this on the EL Escudo Dos. 
// Pin 10 is a status LED on the EL Escudo.  
//  pinMode(10, OUTPUT);

//Pin 13 is the status LED on both the EL Sequencer and Arduino for use with the EL Escudo Dos. 
   pinMode(13, OUTPUT);    
}


/*******************Main Loop***************************/
void loop() 
{
  int x,status;
  
  //Step through all eight EL channels (pins 2 through 9)
  for (x=2; x<=9; x++)
  {
    digitalWrite(x, HIGH);   // turn the EL channel on
    delay(100);              // wait for 1/10 second
    digitalWrite(x, LOW);    // turn the EL channel off

    //digitalWrite(10, status);   //Uncomment this line if using the EL Escudo Dos
    digitalWrite(13, status);	// blink status LEDs
    status = !status; 
  }
}

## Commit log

2015-05-06 Adding hardware files, readme, example sketch
    [SparkFun_EL_Escudo_Dos.brd, SparkFun_EL_Escudo_Dos.sch]
2015-11-12 created new v21 panel
    [SparkFun_EL_Escudo_Dos_Panel_v21.brd]

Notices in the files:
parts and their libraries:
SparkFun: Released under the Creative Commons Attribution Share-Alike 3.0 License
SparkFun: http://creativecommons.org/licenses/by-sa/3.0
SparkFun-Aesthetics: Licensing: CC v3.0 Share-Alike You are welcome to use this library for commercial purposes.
